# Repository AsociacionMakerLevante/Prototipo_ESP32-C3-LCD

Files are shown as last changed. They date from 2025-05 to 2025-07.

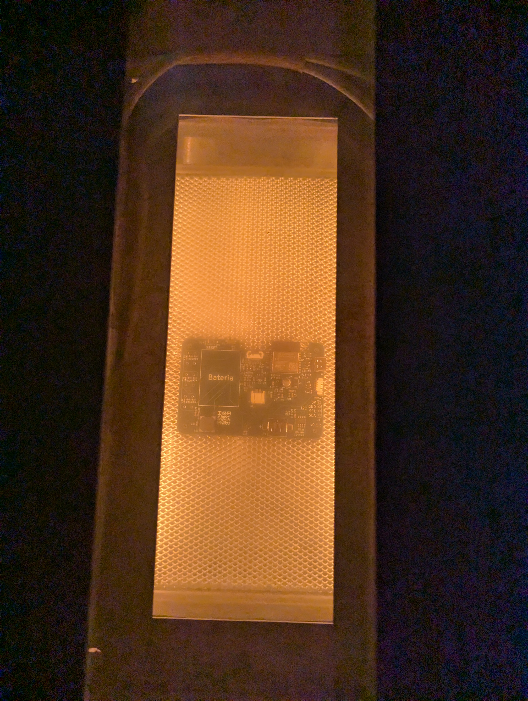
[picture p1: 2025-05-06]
Imagenes/S5.jpg

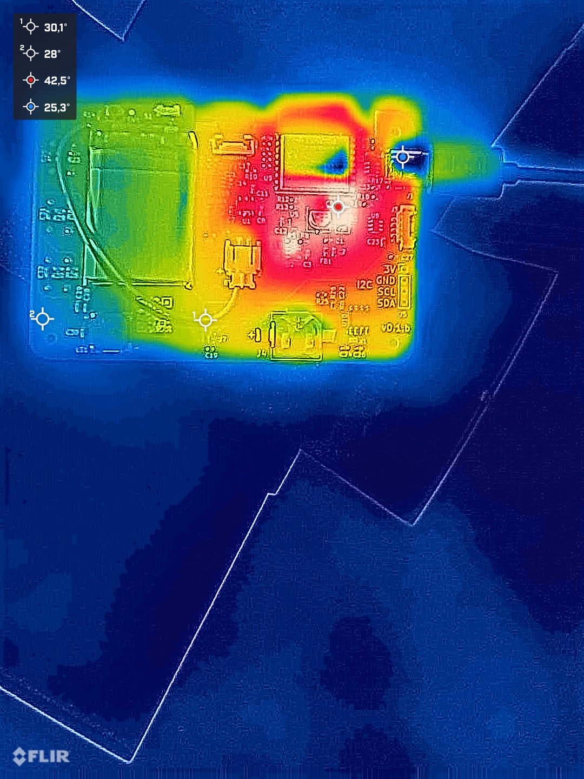
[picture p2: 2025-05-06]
Imagenes/term.JPEG

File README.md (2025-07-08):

# Prototipo_ESP32-C3-LCD
Archivos del prorotipo de la placa para el taller de FreeRTOS, es un diseño rápido con componentes que tenía a mano.. 

Código de prueba para verificar el Hardware, no usar el código como referencia!

No se han medido las señales de la placa con el osciloscopio, por lo que aún está por verificar el correcto funcionamiento del pcb a nivel de señal y consumos de corriente (medir corriente máxima que puede dar el LDO), a nivel de funcionalidad-programación parece correcto.

Cambios hardware para futuras revisiones:
- Condensadores y diodos TVS a la entrada del USB, ver compatibilidad con distintas marcas de cargadores.
- Cambiar la ubicación del sensor de temperatura (se calienta con la batería en carga) y aplicarle un "moat".
- Reducir espacios en las DRC e incrementar algunos planos de disipación térmica (considerar planos de tierra en las capas exteriores).
- Calcular y ajustar los condensadores (2*(Cl-Cs)) del cristal del RTC, medir la desviación de este.
- Reducir el número de valores distintos de resistencias y condensadores en el BOM.
- Mejoras EMI/EMC: filtro pi delante del diodo a continuación del USB, reducir ramificaciones (conexiones punto a punto), stitching vias perímetro, reubicar algunos componentes.

Es un diseño hardware MUY rápido para evaluar la herramienta de KiCad, en ningún caso usar como referencia. 

Si el proyecto tiene interés entre los asistentes a las reuniones de la asociación, se hará una revisión del PCB más despacio: mejorando el esquemático, el ruteado del PCB y buscando optimizar el consumo de corriente seleccionando los distintos componentes de la placa (cuando hay batería cada uA cuenta!).

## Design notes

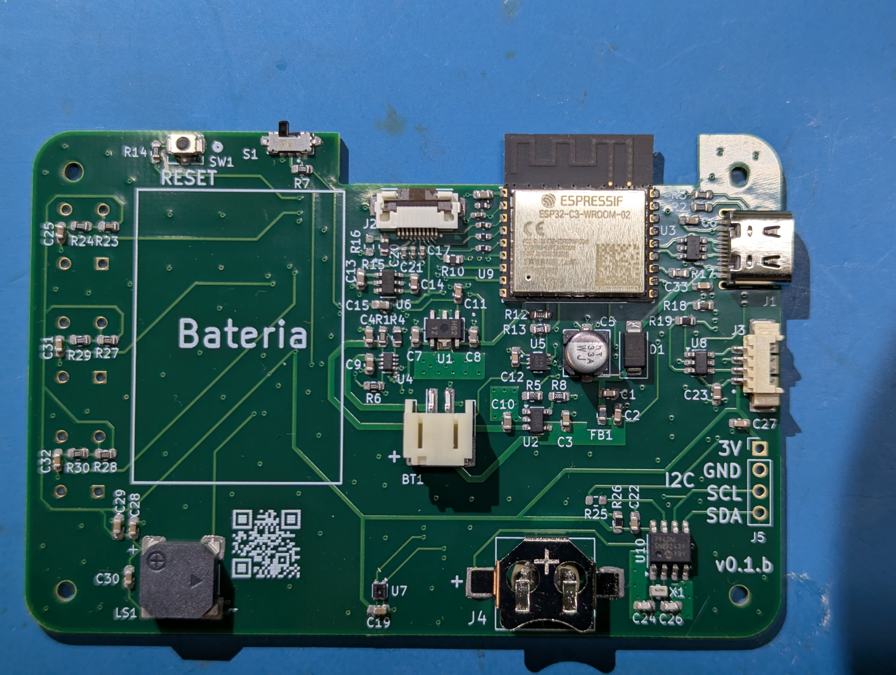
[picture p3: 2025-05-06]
Imagenes/S3.jpg

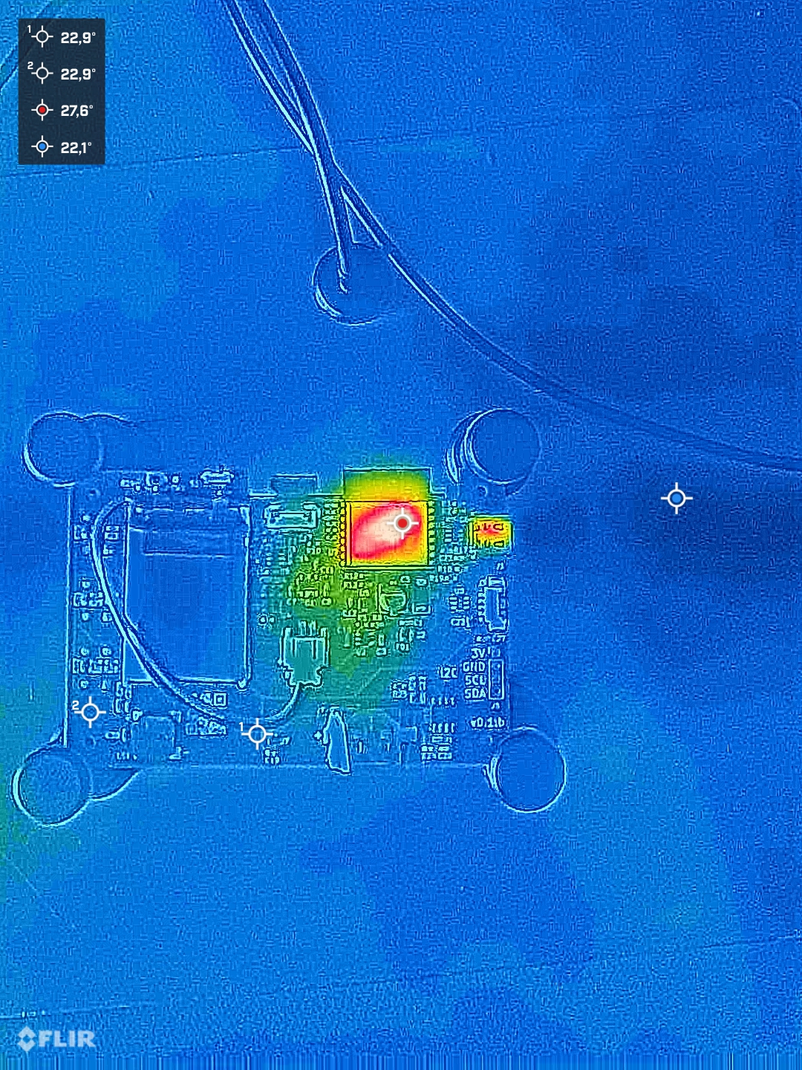
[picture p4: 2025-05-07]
Imagenes/term2_sin_cargar_bateria.JPEG

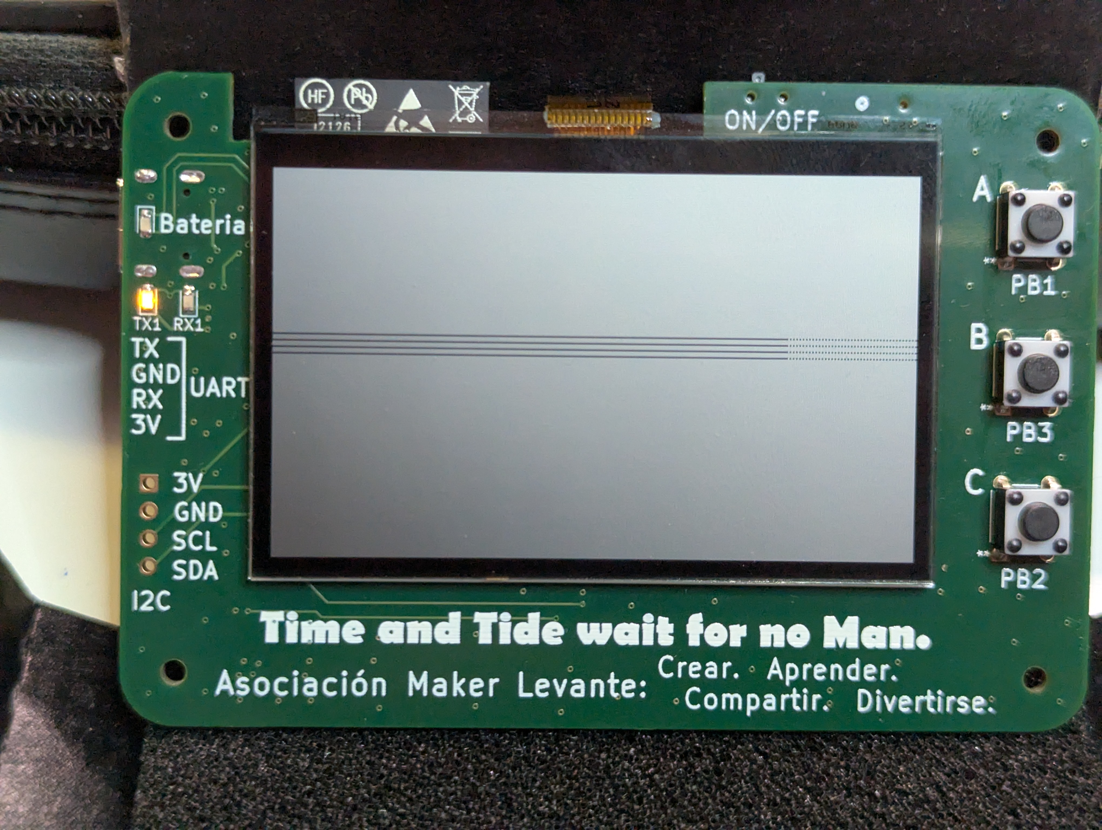
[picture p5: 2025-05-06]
Imagenes/LCD.jpg

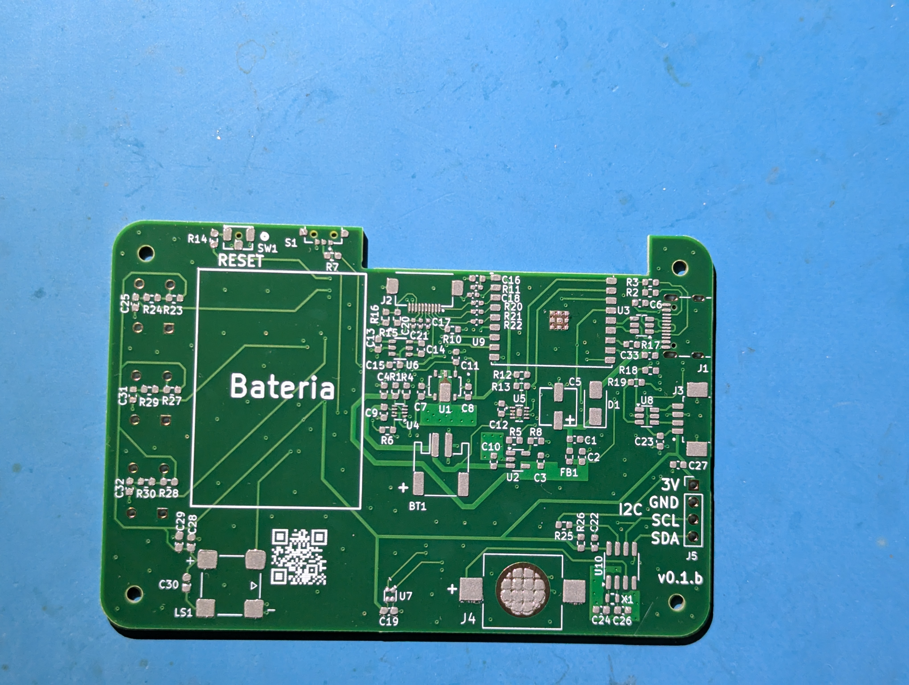
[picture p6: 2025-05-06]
Imagenes/S2.jpg

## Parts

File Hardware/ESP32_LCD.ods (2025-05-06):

Reference | Qty | Value | Footprint | Referencia fabricante
BT1 | 1 | Battery_Cell | Connector_JST:JST_PH_S2B-PH-SM4-TB_1x02-1MP_P2.00mm_Horizontal | S2B-PH-SM4-TB (https://www.digikey.es/es/products/detail/jst-sales-america-inc/S2B-PH-SM4-TB/926655)
C1,C2,C6,C11,C12,C19,C25,C27,C28,C30,C31,C32,C33 | 13 | 100nF | Capacitor_SMD:C_0603_1608Metric | C0603C104K4RACTU (https://www.digikey.es/es/products/detail/kemet/C0603C104K4RACTU/411095)
C4,C9,C14,C23 | 4 | 1uF | Capacitor_SMD:C_0603_1608Metric | C0603C105K4RACTU (https://www.digikey.es/es/products/detail/kemet/C0603C105K4RACTU/2199788)
C5 | 1 | 22uF | UWJ1C220MCL1GB:CAP_UWF_5X5P4_NCH | UWJ1A330MCL1GB (https://www.digikey.es/es/products/detail/nichicon/UWJ1A330MCL1GB/2550753)
C3, C7,C8, C10, C13,C15,C16,C22, C29 | 6 | 10uF | Capacitor_SMD:C_0603_1608Metric | CL10A106KP8NNNC (https://www.digikey.es/es/products/detail/samsung-electro-mechanics/CL10A106KP8NNNC/3886850)
C17,C21 | 2 | 100nF | Capacitor_SMD:C_0402_1005Metric | CL05B104KP5NNNC (https://www.digikey.es/es/products/detail/samsung-electro-mechanics/CL05B104KP5NNNC/3886660)
C18, C20 | 1 | 1uF | Capacitor_SMD:C_0402_1005Metric_Pad0.74x0.62mm_HandSolder | CL05A105KO5NNNC (https://www.digikey.es/es/products/detail/samsung-electro-mechanics/CL05A105KO5NNNC/3886725)
C24,C26 | 2 | 7pF | Capacitor_SMD:C_0603_1608Metric | KGM15ACG1C6R8CT (https://www.digikey.es/es/products/detail/kyocera-avx/KGM15ACG1C6R8CT/3080751)
D1 | 1 | STPS2H100A | Diode_SMD:D_SMA | B240A-13-F (https://www.digikey.es/es/products/detail/diodes-incorporated/B240A-13-F/717691) | STPS2H100A (https://www.digikey.es/es/products/detail/stmicroelectronics/STPS2H100A/691857)
D2,RX1,TX1 | 3 | LED | LED_SMD:LED_0603_1608Metric | 150060YS75000 (https://www.digikey.es/es/products/detail/würth-elektronik/150060YS75000/4489909) | LS Q976-NR-1-0-20-R18 (https://www.digikey.es/es/products/detail/ams-osram-usa-inc/LS-Q976-NR-1-0-20-R18/1227986)
FB1 | 1 | 220R | Resistor_SMD:R_0603_1608Metric | BLM18SG221TN1D (https://www.digikey.es/es/products/detail/murata-electronics/BLM18SG221TN1D/1948330)
J1 | 1 | 12402012E212A | 12402012E212A:AMPHENOL_12402012E212A | 12402012E212A (https://www.digikey.es/es/products/detail/amphenol-cs-commercial-products/12402012E212A/13683192)
J2 | 1 | 528921033 | 0528921033:MOLEX_0528921033 | 528921033 (https://www.digikey.es/es/products/detail/molex/0528921033/4444654)
J3 | 1 | 532610471 | 0532610471:MOLEX_0532610471 | 532610471 (https://www.digikey.es/es/products/detail/wec/532610471/18851293) | 0532610471 (https://www.digikey.es/es/products/detail/molex/0532610471/699096) | 1734261-4
J4 | 1 | BK-870 | BK_870_TR:MPD_BK-870 | BK-870 (https://www.digikey.es/es/products/detail/mpd-memory-protection-devices/BK-870/3829737)
LS1 | 1 | CMI-8536-82-SMT-TR | CMI_8536_82_SMT_TR:CMI-8536-82-SMT-TR | CMI-8536-82-SMT-TR (https://www.digikey.es/es/products/detail/same-sky-formerly-cui-devices/CMI-8536-82-SMT-TR/21407823)
R1,R23,R27,R28 | 4 | 30k | Resistor_SMD:R_0603_1608Metric | CRCW060330K0FKEAC (https://www.digikey.es/es/products/detail/vishay-dale/CRCW060330K0FKEAC/7924022)
R2,R3,R12,R13 | 4 | 5k1 | Resistor_SMD:R_0603_1608Metric | CRCW06035K10FKEAC (https://www.digikey.es/es/products/detail/vishay-dale/CRCW06035K10FKEAC/7928452)
R4 | 1 | 10k | Resistor_SMD:R_0603_1608Metric | CRCW060310K0FKEA (https://www.digikey.es/es/products/detail/vishay-dale/CRCW060310K0FKEA/1174782)
R5,R18,R19 | 3 | 1k | Resistor_SMD:R_0603_1608Metric | CRCW06031K00FKEA (https://www.digikey.es/es/products/detail/vishay-dale/CRCW06031K00FKEA/1174668)
R6 | 1 | 300k | Resistor_SMD:R_0603_1608Metric | CRCW0603300KFKEAC (https://www.digikey.es/es/products/detail/vishay-dale/CRCW0603300KFKEAC/7924230)
R7,R14,R24,R29,R30 | 5 | 100 | Resistor_SMD:R_0603_1608Metric | CRCW0603100RFKEAC (https://www.digikey.es/es/products/detail/vishay-dale/CRCW0603100RFKEAC/7928373)
R8 | 1 | 2k2 | Resistor_SMD:R_0603_1608Metric | CRCW06032K20FKEAC (https://www.digikey.es/es/products/detail/vishay-dale/CRCW06032K20FKEAC/7928444)
R10,R15,R25 | 3 | 0 | Resistor_SMD:R_0603_1608Metric | CRCW06030000Z0EAHP (https://www.digikey.es/es/products/detail/vishay-dale/CRCW06030000Z0EAHP/2222231)
R11 | 1 | 10k | Resistor_SMD:R_0402_1005Metric_Pad0.72x0.64mm_HandSolder | CRCW040210K0FKED (https://www.digikey.es/es/products/detail/vishay-dale/CRCW040210K0FKED/1178121)
R17 | 1 | 330 | Resistor_SMD:R_0603_1608Metric | CRCW0603330RFKEAC (https://www.digikey.es/es/products/detail/vishay-dale/CRCW0603330RFKEAC/7928448)
R20,R21,R22 | 3 | 33 | Resistor_SMD:R_0402_1005Metric_Pad0.72x0.64mm_HandSolder | CRCW040233R0FKED (https://www.digikey.es/es/products/detail/vishay-dale/CRCW040233R0FKED/1177836)
R26 | 1 | 100k | Resistor_SMD:R_0603_1608Metric | CRCW0603100KFKEA (https://www.digikey.es/es/products/detail/vishay-dale/CRCW0603100KFKEA/1174896)
S1 | 1 | SSAJ110100 | SSAJ110100:SW_SSAJ110100 | SSAJ110100 (https://www.digikey.es/es/products/detail/alps-alpine/SSAJ110100/19529200)
SW1 | 1 | B3U-1100P-B | B3U-1100P:B3U-1100P-B_OMR | B3U-1100P-B (https://www.digikey.es/es/products/detail/omron-electronics-inc-emc-div/B3U-1100P-B/1811778)
SW2,SW3,SW4 | 3 | 1825910-6 | 1825910_6:SW4_1825910-B_TEC | 1825910-6 (https://www.digikey.es/es/products/detail/te-connectivity-alcoswitch-switches/1825910-6/1632536)
U1 | 1 | XC6220B331PR-G | XC6220:SOT-89-5_TOR | XC6220B331PR-G (https://www.digikey.es/es/products/detail/torex-semiconductor-ltd/XC6220B331PR-G/2138172) | XC6220B311PR-G (https://www.digikey.es/es/products/detail/torex-semiconductor-ltd/XC6220B311PR-G/10166185) | XC6220B321PR-G (https://www.digikey.es/es/products/detail/torex-semiconductor-ltd/XC6220B321PR-G/10166187)
U2 | 1 | MCP73831-3-OT | Package_TO_SOT_SMD:SOT-23-5 | MCP73831T-2ACI/OT (https://www.digikey.es/es/products/detail/microchip-technology/MCP73831T-2ACI-OT/964301)
U3,U8 | 2 | USBLC6-2SC6 | Package_TO_SOT_SMD:SOT-23-6 | USBLC6-2SC6 (https://www.digikey.es/es/products/detail/stmicroelectronics/USBLC6-2SC6/1040559)
U4 | 1 | TPS2116DRL | Package_TO_SOT_SMD:SOT-583-8 | TPS2116DRLR (https://www.digikey.es/es/products/detail/texas-instruments/TPS2116DRLR/15205127)
U5 | 1 | MAX17048G+T10 | MAX17048:21-0168E_T822-3_MXM | MAX17048G+T10 (https://www.digikey.es/es/products/detail/analog-devices-inc-maxim-integrated/MAX17048G-T10/3758921)
U6 | 1 | AP3602AKTR-G1 | footprints:SOT-23-6_DIO | AP3602AKTR-G1 (https://www.digikey.es/es/products/detail/diodes-incorporated/AP3602AKTR-G1/5305823)
U7 | 1 | SHT4x | Sensor_Humidity:Sensirion_DFN-4_1.5x1.5mm_P0.8mm_SHT4x_NoCentralPad | SHT40-BD1B-R3 (https://www.digikey.es/es/products/detail/sensirion-ag/SHT40-BD1B-R3/19543008)
U9 | 1 | ESP32-C3-WROOM-02 | RF_Module:ESP32-C3-WROOM-02 | ESP32-C3-WROOM-02-N4 (https://www.digikey.es/es/products/detail/espressif-systems/ESP32-C3-WROOM-02-N4/14553031)
U10 | 1 | MCP7940N-xSN | Package_SO:SOIC-8_3.9x4.9mm_P1.27mm | MCP7940NT-I/SN (https://www.digikey.es/es/products/detail/microchip-technology/MCP7940NT-I-SN/2665116)
X1 | 1 | CM8V-T1A-32.768KHZ-7PF-20PPM-TA-QC | CM8V-T1A:CRYSTAL_CM8V-T1A-32.768KHZ-7PF-20PPM-TA-QC_MCX-L | CM8V-T1A-32.768KHZ-7PF-20PPM-TA-QC (https://www.digikey.es/es/products/detail/micro-crystal-ag/CM8V-T1A-32-768KHZ-7PF-20PPM-TA-QC/10499080)

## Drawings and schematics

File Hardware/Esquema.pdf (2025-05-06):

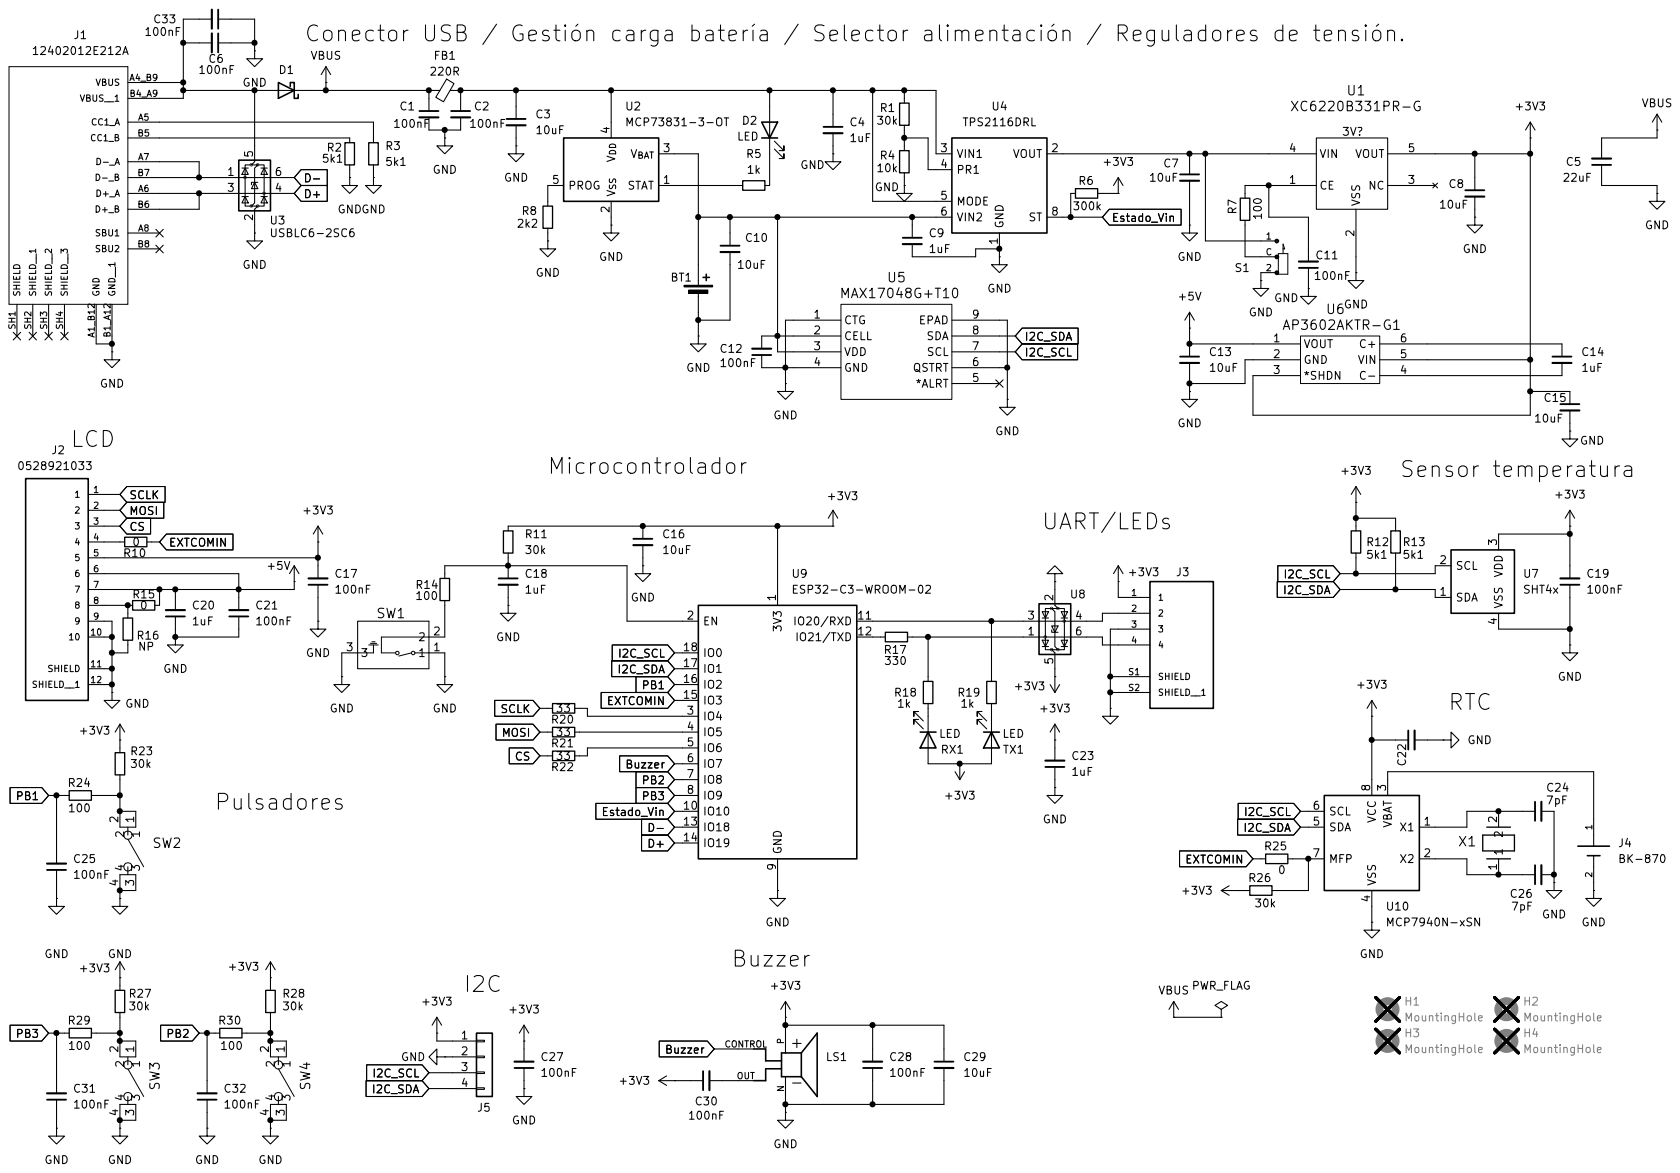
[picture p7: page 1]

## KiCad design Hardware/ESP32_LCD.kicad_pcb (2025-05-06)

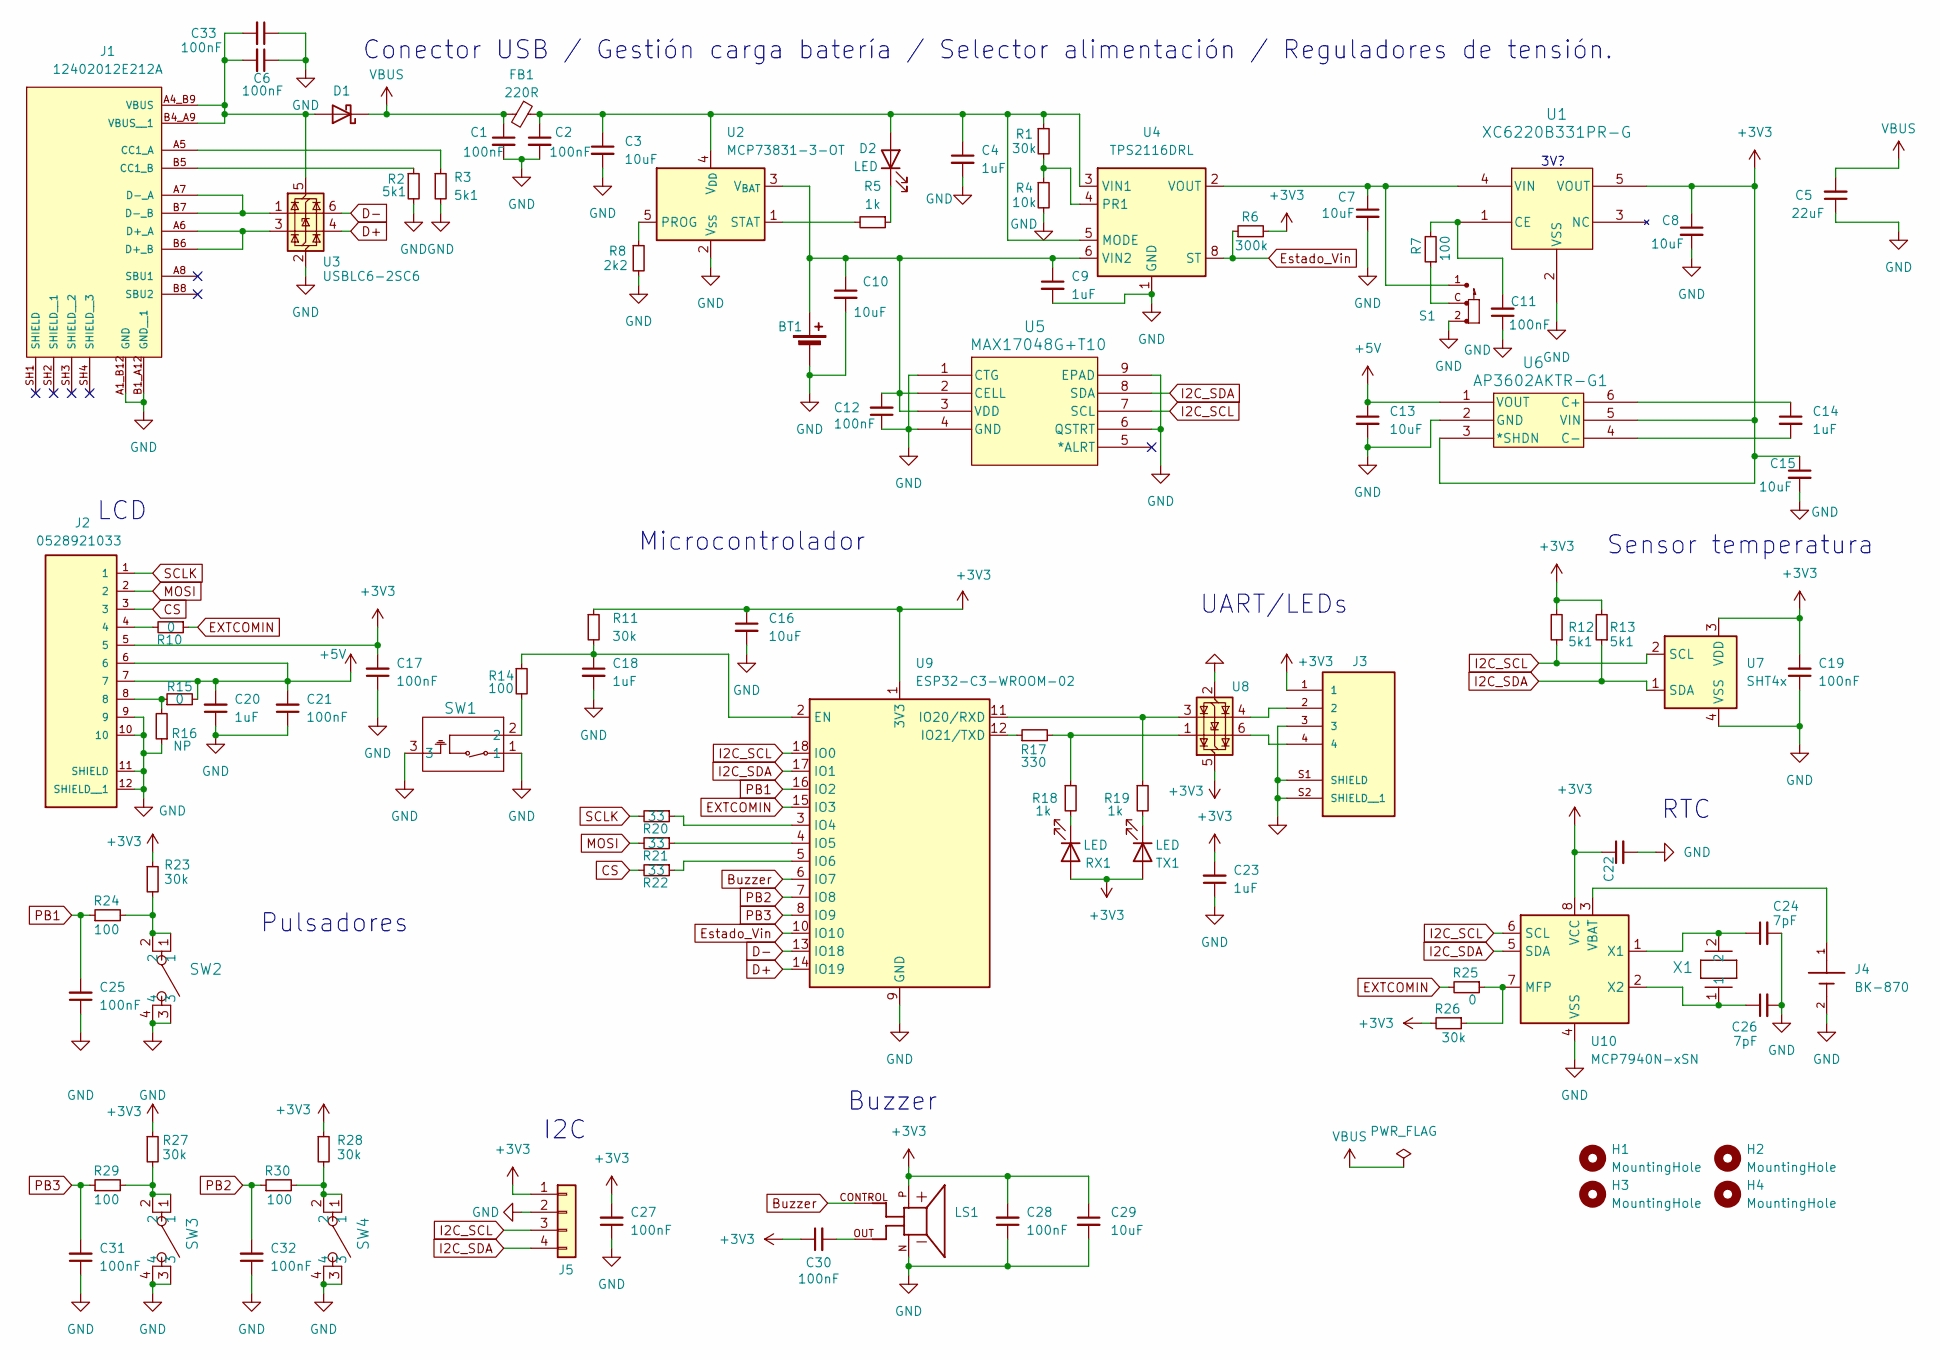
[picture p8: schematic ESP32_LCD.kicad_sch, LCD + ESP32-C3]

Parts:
BT1: Battery_Cell; JST_PH_S2B-PH-SM4-TB_1x02-1MP_P2.00mm_Horizontal
C1, C2, C6, C11, C12, C19, C25, C27, C28, C30, C31, C32, C33: 100nF; C_0603_1608Metric
C3, C7, C8, C10, C13, C15, C16, C22: 10uF; C_0603_1608Metric
C4, C9, C14, C23: 1uF; C_0603_1608Metric
C5: 22uF; CAP_UWF_5X5P4_NCH
C17, C21: 100nF; C_0402_1005Metric
C18: 1uF; C_0402_1005Metric_Pad0.74x0.62mm_HandSolder
C20: 1uF; C_0402_1005Metric
C24, C26: 7pF; C_0603_1608Metric
C29: 10uF; C_0603_1608Metric_Pad1.08x0.95mm_HandSolder
D1: 1N5819; D_SMA
D2: LED; LED_0603_1608Metric
FB1: 220R; R_0603_1608Metric
H1, H2, H3, H4: MountingHole; MountingHole_2.2mm_M2_ISO14580
J1: 12402012E212A; AMPHENOL_12402012E212A; PARTREV 4
J2: 0528921033; MOLEX_0528921033
J3: 0532610471; MOLEX_0532610471; PARTREV J
J4: BK-870; MPD_BK-870; PARTREV D
J5: Conn_01x04; PinHeader_1x04_P2.54mm_Vertical
LS1: CMI-8536-82-SMT-TR; PARTREV 1.01
R1, R23, R26, R27, R28: 30k; R_0603_1608Metric
R2, R3, R12, R13: 5k1; R_0603_1608Metric
R4: 10k; R_0603_1608Metric
R5, R18, R19: 1k; R_0603_1608Metric
R6: 300k; R_0603_1608Metric
R7, R14, R24, R29, R30: 100; R_0603_1608Metric
R8: 2k2; R_0603_1608Metric
R10, R15, R25: 0; R_0603_1608Metric
R11: 30k; R_0402_1005Metric_Pad0.72x0.64mm_HandSolder
R16: NP; R_0603_1608Metric
R17: 330; R_0603_1608Metric
R20, R21, R22: 33; R_0402_1005Metric_Pad0.72x0.64mm_HandSolder
RX1: LED; LED_0603_1608Metric
S1: SSAJ110100; SW_SSAJ110100; PARTREV N/A
SW1: B3U-1100P-B; B3U-1100P-B_OMR
SW2, SW3, SW4: 1825910-6; SW4_1825910-B_TEC
TX1: LED; LED_0603_1608Metric
U1: XC6220B331PR-G; SOT-89-5_TOR
U2: MCP73831-3-OT; SOT-23-5
U3, U8: USBLC6-2SC6; SOT-23-6
U4: TPS2116DRL; SOT-583-8
U5: MAX17048G+T10; 21-0168E_T822-3_MXM
U6: AP3602AKTR-G1; SOT-23-6_DIO
U7: SHT4x; Sensirion_DFN-4_1.5x1.5mm_P0.8mm_SHT4x_NoCentralPad
U9: ESP32-C3-WROOM-02
U10: MCP7940N-xSN; SOIC-8_3.9x4.9mm_P1.27mm
X1: CM8V-T1A-32.768KHZ-7PF-20PPM-TA-QC; CRYSTAL_CM8V-T1A-32.768KHZ-7PF-20PPM-TA-QC_MCX-L

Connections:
+3V3: C8.1, C15.1, C16.1, C17.2, C19.2, C22.1, C23.2, C27.2, C28.2, C29.1, C30.1, J2.5, J3.1, J5.1, LS1.P, R6.2, R11.1, R12.2, R13.2, R23.1, R26.2, R27.1, R28.1, RX1.2 (A), TX1.2 (A), U1.5 (VOUT), U6.3 (*SHDN), U6.5 (VIN), U7.3 (VDD), U8.5 (VBUS), U9.1 (3V3), U10.8 (VCC)
+5V: C13.1, C20.2, C21.2, J2.6, J2.7, R15.2, U6.1 (VOUT)
Buzzer: LS1.CONTROL, U9.6 (IO7)
CS: J2.3, R22.2
D+: U3.4 (I/O2), U9.14 (IO19)
D-: U3.6 (I/O1), U9.13 (IO18)
EXTCOMIN: R10.1, R25.2, U9.15 (IO3)
Estado_Vin: R6.1, U4.8 (ST), U9.10 (IO10)
GND: BT1.2 (-), C1.2, C2.2, C3.2, C4.2, C5.1, C6.1, C7.2, C8.2, C9.2, C10.2, C11.1, C12.1, C13.2, C15.2, C16.2, C17.1, C18.2, C19.1, C20.1, C21.1, C22.2, C23.1, C24.2, C25.1, C26.2, C27.1, C28.1, C29.2, C31.1, C32.1, C33.1, J1.A1_B12 (GND), J1.B1_A12 (GND__1), J2.9, J2.10, J2.11 (SHIELD), J2.12 (SHIELD__1), J3.3, J3.S1 (SHIELD), J3.S2 (SHIELD__1), J4.2, J5.2, LS1.N, R2.2, R3.2, R4.2, R8.2, R16.1, S1.2, SW1.1, SW1.3, SW2.3, SW2.4, SW3.3, SW3.4, SW4.3, SW4.4, U1.2 (VSS), U2.2 (V_{SS}), U3.2 (GND), U4.1 (GND), U5.1 (CTG), U5.4 (GND), U5.6 (QSTRT), U5.9 (EPAD), U6.2 (GND), U7.4 (VSS), U8.2 (GND), U9.9 (GND), U9.19 (GND), U10.4 (VSS)
I2C_SCL: J5.3, R12.1, U5.7 (SCL), U7.2 (SCL), U9.18 (IO0), U10.6 (SCL)
I2C_SDA: J5.4, R13.1, U5.8 (SDA), U7.1 (SDA), U9.17 (IO1), U10.5 (SDA)
MOSI: J2.2, R21.2
unnamed: BT1.1 (+), C9.1, C10.1, C12.2, U2.3 (V_{BAT}), U4.6 (VIN2), U5.2 (CELL), U5.3 (VDD)
unnamed: C30.2, LS1.OUT
unnamed: C6.2, C33.2, D1.2 (A), J1.A4_B9 (VBUS), J1.B4_A9 (VBUS__1), U3.5 (VBUS)
unnamed: C2.1, C3.1, C4.1, D2.2 (A), FB1.1, R1.1, U2.4 (V_{DD}), U4.3 (VIN1), U4.5 (MODE)
unnamed: D2.1 (K), R5.1
unnamed: J1.A5 (CC1_A), R3.1
unnamed: J1.B5 (CC1_B), R2.1
unnamed: J1.A6 (D+_A), J1.B6 (D+_B), U3.3 (I/O2)
unnamed: J1.A7 (D-_A), J1.B7 (D-_B), U3.1 (I/O1)
unnamed: J2.4, R10.2
unnamed: J2.8, R15.1, R16.2
unnamed: J3.2, U8.4 (I/O2)
unnamed: J3.4, U8.6 (I/O1)
unnamed: R7.1, S1.C
unnamed: R14.2, SW1.2
unnamed: R17.2, R18.1, U8.1 (I/O1)
unnamed: R23.2, R24.2, SW2.1, SW2.2
unnamed: R27.2, R29.2, SW3.1, SW3.2
unnamed: R28.2, R30.2, SW4.1, SW4.2
unnamed: R18.2, RX1.1 (K)
unnamed: R19.2, TX1.1 (K)
unnamed: C11.2, R7.2, U1.1 (CE)
unnamed: C7.1, S1.1, U1.4 (VIN), U4.2 (VOUT), U4.7 (VOUT)
unnamed: R8.1, U2.5 (PROG)
unnamed: R5.2, U2.1 (STAT)
unnamed: R1.2, R4.1, U4.4 (PR1)
unnamed: C14.1, U6.6 (C+)
unnamed: C14.2, U6.4 (C-)
unnamed: C18.1, R11.2, R14.1, U9.2 (EN)
unnamed: R20.1, U9.3 (IO4)
unnamed: R21.1, U9.4 (IO5)
unnamed: R22.1, U9.5 (IO6)
unnamed: R19.1, U8.3 (I/O2), U9.11 (IO20/RXD)
unnamed: R17.1, U9.12 (IO21/TXD)
unnamed: R25.1, R26.1, U10.7 (MFP)
unnamed: J4.1, U10.3 (VBAT)
unnamed: C24.1, U10.1 (X1), X1.2
unnamed: C26.1, U10.2 (X2), X1.1
PB1: C25.2, R24.1, U9.16 (IO2)
PB2: C32.2, R30.1, U9.7 (IO8)
PB3: C31.2, R29.1, U9.8 (IO9)
SCLK: J2.1, R20.2
VBUS: C1.1, C5.2, D1.1 (K), FB1.2

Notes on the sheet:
Sensor temperatura
UART/LEDs
Conector USB / Gestión carga batería / Selector alimentación / Reguladores de tensión.
LCD
3V?
Pulsadores
Microcontrolador
Buzzer
RTC
I2C

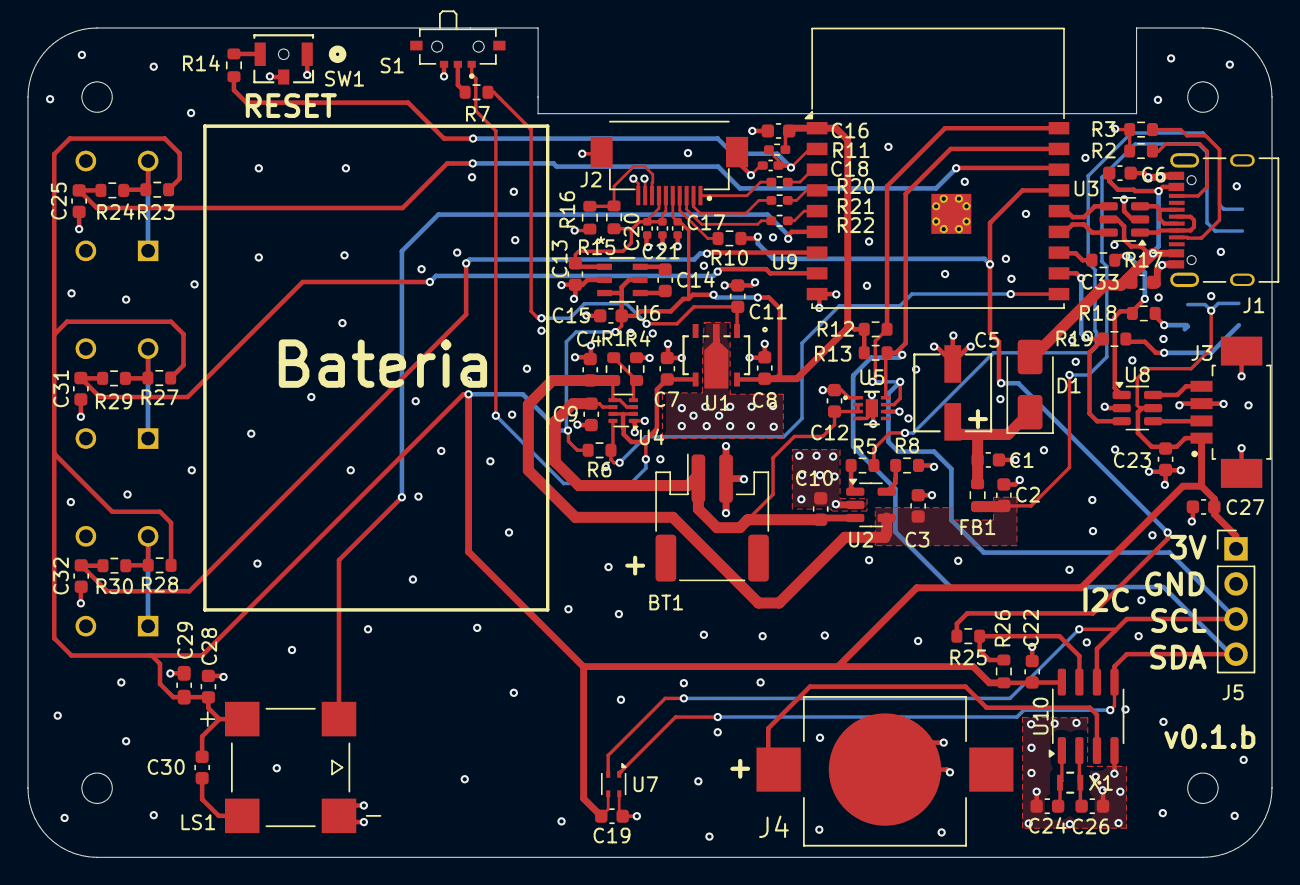
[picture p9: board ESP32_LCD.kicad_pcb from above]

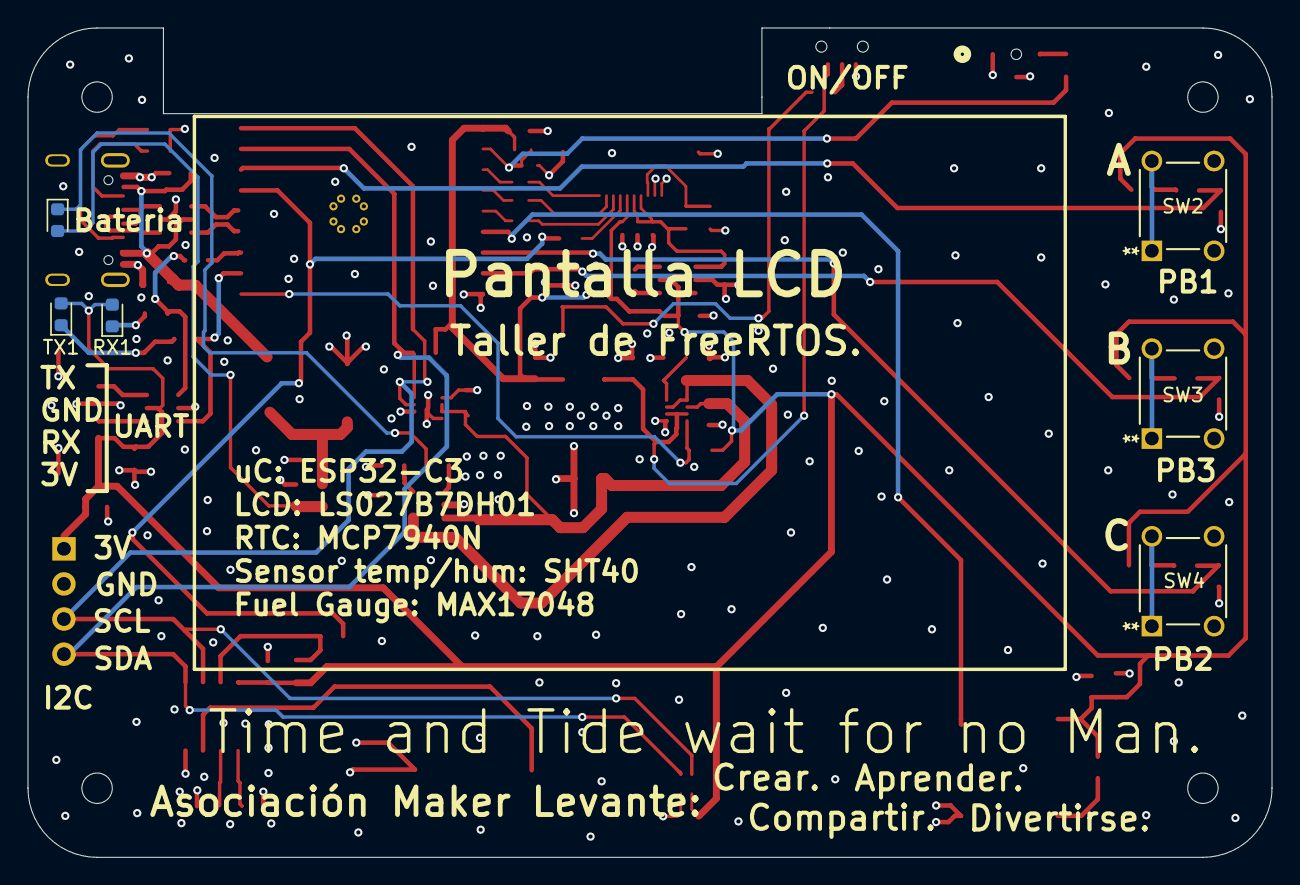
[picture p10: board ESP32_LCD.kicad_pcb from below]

Board: 4 copper layers, 90.0 x 60.0 mm, 94 parts (6 on the bottom side), 55 nets.

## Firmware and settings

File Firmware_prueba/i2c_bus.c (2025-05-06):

/*
Funciones para controlar el bus I2C
https://docs.espressif.com/projects/esp-idf/en/v5.4.1/esp32c3/api-reference/peripherals/i2c.html
*/
#include <stdio.h>
#include "driver/gpio.h"
#include "freertos/FreeRTOS.h"
#include "freertos/task.h"
#include "driver/i2c_master.h"
#include "i2c_bus.h"
#include "pinOut.h"

#define STACK_SIZE 8048 //Stack de las tareas.
//SHT40
#define BYTES_TRANSMISION 1
#define BYTES_RECEPCION 6
#define COMANDO_SHT40_LEER 0xFD
//MAX17048
#define MAX17040_VCELL	0x02
#define MAX17040_SOC	0x04
//RTC MCP7940N
//#define FIJAR_HORA_RTC //Una vez grabado deshabilitar y volver a programar para que el RTC conserve la hora.

//Reserva en RAM del stack and task control block (TCB) para las tareas creadas estáticas
static StackType_t stack_tarea_i2c[STACK_SIZE];
static StaticTask_t TCB_tarea_i2c;
//Declaramos los handlers para las tasks estáticas por si queremos suspenderlas desde otras tasks.
TaskHandle_t xHandle_i2c_crear_tarea_i2c = NULL;

//Función asignada a la tarea i2c
static void tarea_i2c(void *pvParameters);

/************** Definición de las funciones ****************************/

//Función para crear la tarea con la que se pruena el bus i2c
void i2c_crear_tarea_i2c(void)
{
    xHandle_i2c_crear_tarea_i2c = xTaskCreateStatic(
        &tarea_i2c,              //Función que se asigna a al tarea.
        "tarea_i2c",           //Nombre que le asignamos a la tarea (debug). 
        STACK_SIZE,            //Tamaño del stack de la tarea (reservado de manera estática previamente).
        NULL,                  //Parámetros pasados a la tarea en su creación.
        tskIDLE_PRIORITY + 1,  //Prioridad de la tarea. 
        stack_tarea_i2c,       //Array para el stack de la tarea reservado previamente. 
        &TCB_tarea_i2c);       //Memoria reservada previamente para el TCB (task control block) de la tarea.
    
        printf("Tarea para probar el bus I2C creada.\n");  
}

static void tarea_i2c(void *pvParameters)
{
    //Configuramos el ESP como maestro.
    i2c_master_bus_config_t i2c_mst_config = {
        .clk_source = I2C_CLK_SRC_DEFAULT,
        .i2c_port = 0,
        .scl_io_num = I2C_SCL,
        .sda_io_num = I2C_SDA,
        .glitch_ignore_cnt = 7,
        .flags.enable_internal_pullup = true,
    };

    i2c_master_bus_handle_t bus_handle;
    ESP_ERROR_CHECK(i2c_new_master_bus(&i2c_mst_config, &bus_handle));

    //Añadimos el SHT40 al bus I2C
    i2c_device_config_t sht40_cfg = {
        .dev_addr_length = I2C_ADDR_BIT_LEN_7,
        .device_address = 0x45,
        .scl_speed_hz = 100000,
    };
    i2c_master_dev_handle_t sht40_handle;
    ESP_ERROR_CHECK(i2c_master_bus_add_device(bus_handle, &sht40_cfg, &sht40_handle));

    //Añadimos el MAX17048 al bus I2C
    i2c_device_config_t max17048_cfg = {
        .dev_addr_length = I2C_ADDR_BIT_LEN_7,
        .device_address = 0x36,
        .scl_speed_hz = 100000,
    };
    i2c_master_dev_handle_t max17048_handle;
    ESP_ERROR_CHECK(i2c_master_bus_add_device(bus_handle, &max17048_cfg, &max17048_handle));

    //Añadimos el MCP7940N al bus I2C
    i2c_device_config_t mcp7940n_cfg = {
        .dev_addr_length = I2C_ADDR_BIT_LEN_7,
        .device_address = 0x6F,
        .scl_speed_hz = 100000,
    };
    i2c_master_dev_handle_t mcp7940n_handle;
    ESP_ERROR_CHECK(i2c_master_bus_add_device(bus_handle, &mcp7940n_cfg, &mcp7940n_handle));

    //Variables para el SHT40
    uint8_t data_wr[1];
    uint8_t data_rd[6];
    float temperatura = 0;
    float humedad = 0;
    int temperatura_recibida = 0;
    int humedad_recibida = 0;

    //Variables para el MAX17048
    uint8_t max_data_wr[1];
    uint8_t max_data_rd[2];
    float voltaje = 0;
    uint8_t soc = 0;

    //Variables para el MCP7940N
    uint8_t mcp_data_wr[2] = {0, 0};
    uint8_t mcp_data_rd[3] = {0, 0, 0};
    uint8_t segundos_bcd = 0;
    uint8_t minutos_bcd = 0;
    uint8_t horas_bcd = 0;
    uint8_t segundos = 0;
    uint8_t minutos = 0;
    uint8_t horas = 0;
    uint8_t diaSemana = 0;
    uint8_t diaMes = 0;
    uint8_t mes = 0;
    uint8_t year = 0;

    while(1)
    {
        //Leemos el sensor SHT40 e imprimimos sus lecturas.
        data_wr[0] = COMANDO_SHT40_LEER; 
        ESP_ERROR_CHECK(i2c_master_transmit(sht40_handle, data_wr, BYTES_TRANSMISION, -1));
        vTaskDelay(10 / portTICK_PERIOD_MS);
        i2c_master_receive(sht40_handle, data_rd, BYTES_RECEPCION, -1);
        //Calculamos los valores de temperatura y humedad recibidos.
        temperatura_recibida = (data_rd[0]*256L) + data_rd[1];
        temperatura = -45 + 175*(temperatura_recibida/65535.0f);
        humedad_recibida = (data_rd[3]*256L) + data_rd[4];
        humedad = -6 + 125*(humedad_recibida/65535.0f);
        //Imprimimos los valores de temperatura y humedad
        printf("Lectura SHT40: Temperatura %.1f.\n", temperatura);
        printf("Lectura SHT40: Humedad %.1f.\n", humedad);

        //Leemos el MAX17048 e imprimimos sus lecturas.
        max_data_wr[0] = MAX17040_SOC; //Registro con el valor del SOC.
        ESP_ERROR_CHECK(i2c_master_transmit_receive(max17048_handle, max_data_wr, sizeof(max_data_wr), max_data_rd, 2, -1));
        //Calculamos el valor del SOC.
        soc = max_data_rd[0];
        printf("Lectura MAX17040: Porcentaje de bateria %u %%.\n", soc);
        max_data_wr[0] = MAX17040_VCELL; //Registro con el valor de Vcell
        ESP_ERROR_CHECK(i2c_master_transmit_receive(max17048_handle, max_data_wr, sizeof(max_data_wr), max_data_rd, 2, -1));
        //Calculamos el valor de Vcell.
        voltaje = ((max_data_rd[0]*256L + max_data_rd[1])*78.125f)/1000000;
        printf("Lectura MAX17040: Voltaje de bateria %.3f V.\n", voltaje);
        //ESP_ERROR_CHECK(i2c_master_transmit_receive(max17048_handle, max_data_wr, sizeof(max_data_wr), max_data_rd, 2, -1));
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

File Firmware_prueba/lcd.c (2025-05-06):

/*
Funciones para controlar la pantalla LCD
*/
#include <stdio.h>
#include "driver/gpio.h"
#include "lcd.h"
#include "freertos/FreeRTOS.h"
#include "freertos/task.h"
#include "driver/spi_master.h"
#include "esp_log.h"
#include "pinOut.h"

#define STACK_SIZE 2048 //Stack de las tareas.

enum estadoPIN {OFF, ON}; 
enum LCD_Comando{VCOM = 0x00, LIMPIAR = 0x04, ESCRIBIR = 0x01};

//Reserva en RAM del stack and task control block (TCB) para las tareas creadas estáticas
static StackType_t stack_tarea_LCD[STACK_SIZE];
static StaticTask_t TCB_tarea_LCD;
//Declaramos los handlers para las tasks estáticas por si queremos suspenderlas desde otras tasks.
TaskHandle_t xHandle_lcd_crear_tarea = NULL;

//Dispositivo SPI que vamos a controlar.
spi_device_handle_t spi_device_LCD;

//Función que asignamos a la tarea del LCD.
static void lcd_LCD(void *pvParameters);

//Función para conmutar LCD EXTCON
static void lcd_extcon(enum estadoPIN estado);

//Funciones para la transmisión SPI.
static void lcd_spi_init(void);
static void lcd_spi_escribir_linea(uint8_t linea, uint8_t *data);
static void lcd_limpiar_pantalla();

/**************Definición de las funciones ***********************/

//Definición de la función que crea la tarea para controlar el LCD.
void lcd_crear_tarea_LCD(void)
{
    xHandle_lcd_crear_tarea = xTaskCreateStatic(
        &lcd_LCD,              //Función que se asigna a al tarea.
        "tarea_LCD",           //Nombre que le asignamos a la tarea (debug). 
        STACK_SIZE,            //Tamaño del stack de la tarea (reservado de manera estática previamente).
        NULL,                  //Parámetros pasados a la tarea en su creación.
        tskIDLE_PRIORITY + 2,  //Prioridad de la tarea. 
        stack_tarea_LCD,       //Array para el stack de la tarea reservado previamente. 
        &TCB_tarea_LCD);       //Memoria reservada previamente para el TCB (task control block) de la tarea.
    
        printf("Tarea para controlar el LCD creada.\n");  
}

//Función que asignamos a la tarea del LCD.
static void lcd_LCD(void *pvParameters)
{
    TickType_t xLastWakeTime;
    enum estadoPIN estado = OFF;

    // Inicializa xLastWakeTime con el tiempo actual.
    xLastWakeTime = xTaskGetTickCount();

    //Inicializamos el hardware conectado al LCD.
    lcd_spi_init();
    lcd_limpiar_pantalla();

    //Línea que se va a escribir.
    uint8_t linea = 127;    
    //contenido de la línea. (en el stack de la tarea)
    uint8_t  data_linea[52] = { 0xAA, 0xAA, 0xAA, 0xAA, 0xAA, 0xAA, 0xAA, 0xAA, 0xAA, 0xAA,
        0x00, 0x00, 0x00, 0x00, 0x00, 0x00, 0x00, 0x00, 0x00, 0x00,
        0x00, 0x00, 0x00, 0x00, 0x00, 0x00, 0x00, 0x00, 0x00, 0x00,
        0x00, 0x00, 0x00, 0x00, 0x00, 0x00, 0x00, 0x00, 0x00, 0x00,
        0x00, 0x00, 0x00, 0x00, 0x00, 0x00, 0x00, 0x00, 0x00, 0x00,
        0x00, 0x00 };

    while(1)
    {
        //InvertimosEXTCON
        estado = !estado;
        lcd_extcon(estado);

        if(estado == true)
        {
            //Limpiamos la pantalla.
            lcd_limpiar_pantalla();
            //Escribimos líneas en la pantalla.
            lcd_spi_escribir_linea(linea, data_linea);
            lcd_spi_escribir_linea((linea + 4), &data_linea[0]);
            lcd_spi_escribir_linea((linea + 8), data_linea);
            lcd_spi_escribir_linea((linea + 12), data_linea);
        }
        else
        {
            //Limpiamos la pantalla.
            lcd_limpiar_pantalla();
            //Escribimos líneas en la pantalla
            lcd_spi_escribir_linea((linea + 16), data_linea);
            lcd_spi_escribir_linea((linea + 20), data_linea);
            lcd_spi_escribir_linea((linea + 24), data_linea);
            lcd_spi_escribir_linea((linea + 28), data_linea);
        }
        //Bloqueamos la tarea durante 500 ms
        vTaskDelayUntil( &xLastWakeTime, (500 / portTICK_PERIOD_MS) );
    }
}

//Funcion para conmutar LCD EXTCON
static void lcd_extcon(enum estadoPIN estado)
{
    gpio_set_level(LCD_EXTCON, estado);
}

//Declaración de las funciones para la transmisión SPI.
static void lcd_spi_init(void)
{
   //Configuramos el pin de LCD EXTCON como salida.
   gpio_reset_pin(LCD_EXTCON);
   gpio_set_direction(LCD_EXTCON, GPIO_MODE_OUTPUT);
   gpio_pullup_dis(LCD_EXTCON);
   gpio_set_level(LCD_EXTCON, 0);

    //Inicializar el bus SPI llamando a spi_bus_initialize().
    //Estructura de inicialización spi_bus_config_t.
    spi_bus_config_t conf_bus_SPI = {
        .mosi_io_num = SPI_MOSI,
        .miso_io_num = -1,
        .sclk_io_num = SPI_CLK,
        .quadwp_io_num = -1,
        .quadhd_io_num = -1,
        .data4_io_num = -1,
        .data5_io_num = -1,
        .data6_io_num = -1,
        .data7_io_num = -1,
        .data_io_default_level = 0,
        .max_transfer_sz = SOC_SPI_MAXIMUM_BUFFER_SIZE,
        .flags = SPI_DEVICE_POSITIVE_CS,
    };
    spi_bus_initialize(SPI2_HOST, &conf_bus_SPI, SPI_DMA_DISABLED);

    //Registrar el dispositivo LCD en el bus SPI llamando a spi_bus_add_device();
    //Estrucutura spi_device_interface_config_t.
    spi_device_interface_config_t conf_interfaz_SPI =
    {
        .command_bits = 8,
        .address_bits = 8,
        .dummy_bits = 0,
        .mode = 0, 
        .clock_source = SPI_CLK_SRC_DEFAULT,
        .duty_cycle_pos = 0,
        .cs_ena_pretrans = 0,
        .cs_ena_posttrans = 0,
        .clock_speed_hz = 2000000UL,
        .input_delay_ns = 0,
        .spics_io_num = SPI_CS,
        .flags = (SPI_DEVICE_POSITIVE_CS | SPI_DEVICE_TXBIT_LSBFIRST),
        .queue_size = 1,
        //.pre_cb = NULL,
        //.post_cb = NULL,
    };
    spi_bus_add_device(SPI2_HOST, &conf_interfaz_SPI, &spi_device_LCD);

    //Ponemos a 1 EXTCOM
    gpio_set_level(LCD_EXTCON, 1);
    vTaskDelay(10 / portTICK_PERIOD_MS); 
}
static void lcd_spi_escribir_linea(uint8_t linea, uint8_t *data)
{
    enum LCD_Comando comando = ESCRIBIR;

    //Para interactura con el dispositivo rellenar la estructura spi_transaction_t.
    //funciones spi_device_queue_trans()  o spi_device_polling_transmit() 
    //Escribimos una línea. El LCD recibe el LSB primero
    spi_transaction_t spi_envio_LCD =
    {
        //.flags = NULL,
        .cmd = comando,
        .addr = linea,
        .length = 416,
        .rxlength = 0,
        .user = NULL,
        .tx_buffer = data, //no poner &data, si no el contenido, la dirección a la que apunta data.
        .rx_buffer = NULL,
    };
    spi_device_polling_transmit(spi_device_LCD, &spi_envio_LCD); 
}
static void lcd_limpiar_pantalla()
{
    //Limpiar pantalla.

    enum LCD_Comando comando = LIMPIAR ;

    spi_transaction_t spi_envio_LCD_CS =
    {
        //.flags = NULL,
        .cmd = comando,
        .addr = 0b00000000,
        .length = 0,
        .rxlength = 0,
        .user = NULL,
        .tx_buffer = NULL,
        .rx_buffer = NULL,
    };
    spi_device_polling_transmit(spi_device_LCD, &spi_envio_LCD_CS);
}
